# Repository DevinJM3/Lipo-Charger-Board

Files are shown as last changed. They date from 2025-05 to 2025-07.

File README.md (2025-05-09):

# LiPo Charger & Protection Board with 5V Output

PLACEHOLDER FOR IMAGE

## Overview

This project is a custom-designed Lithium Polymer battery charging and protection circuit with a regulated 5V output. Perfect for powering your portable electronics projects, this board offers a complete power management solution in a compact form factor.

## Features

- **LiPo Battery Charging**: Safe charging circuit for single-cell LiPo batteries
- **Battery Protection**: Overcharge, over-discharge, and short-circuit protection
- **5V Regulated Output**: Clean, stable 5V output regardless of battery voltage
- **Compact Design**: Minimized footprint for easy integration into projects
- **Status Indicators**: LED indicators for charging/full charge
- **USB Input**: Standard USB-C connector for charging and power input

## Technical Specifications

- **Input Voltage**: 5V DC via USB
- **Battery**: Single-cell 3.7V Lithium Polymer
- **Charging Current**: 500mA (configurable)
- **Output Voltage**: 5V ±0.1V
- **Maximum Output Current**: 2A continuous
- **Protection Features**:
  - Overcharge cutoff: 4.2V
  - Over-discharge cutoff: 2.8V
  - Short-circuit protection

## PCB Details

- **Dimensions**: XX mm × XX mm
- **Layers**: 2-layer PCB
- **Designed with**: KiCad 9.0

## Getting Started

### Bill of Materials

| Designator | Footprint | Quantity | Value | LCSC Part # |
|---|---|---|---|---|
| C1, C2 |0603 |2 |10uF |C19702 |
| C3 |0603 |1 |0.1uF |C14663 |
| C4, C5 |0603 |2 |22uF |C59461 |
| D1 |0603 |1 |RED |C965799 |
| D2 |0603 |1 |GREEN |C19171301 |
| D3 |D_SMA-SMB_Universal_Handsoldering |1 |SS34 |C908680 |
| D4, D5 |D_SMA-SMB_Universal_Handsoldering |2 |B340A |C85098 |
| D6 |Nexperia_CFP3_SOD-123W |1 |5.1v |C19077401 |
| J1 |JST_S2B-XH-A |1 |S2B-XH-A |C157931 |
| J2 |Usb-C |1 |USB_C_USB2.0_14P |C2988369 |
| L1 |WE-PD2_1054 |1 |22uH |C436465 |
| Q1, Q2 |SOT-23_Handsoldering |2 |SI2300A |C347480 |
| R1, R5 |0603 |2 |2k |C2907022 |
| R10 |0603 |1 |73.2k |C2933257 |
| R11, R7 |0603 |2 |10k |C98220 |
| R2, R3 |0603 |2 |1k |C103198 |
| R4 |0603 |1 |100 |C3016239 |
| R6 |0603 |1 |0.4 |C5126047 |
| R8, R9 |0603 |2 |5.1k |C3016319 |
| SW1 |SlideSwitch |1 |SK12D07VG4 |C393937 |
| U1 |SOIC-8 |1 |TP4056-42-ESOP8  |C725790 |
| U2 |SOT-23-6 |1 |MT3608 |C84817 |
| U3 |TSOT-23-6_HandSoldering |1 |FM2113 |C2832124 |

## Usage

1. Connect a LiPo battery to the BAT+ and BAT- terminals
2. Power the board via the USB connector
3. Connect your load to the 5V and GND output terminals
4. The charging indicator LED will illuminate red during charging and turn green when complete

## License

This project is released under the [MIT License](LICENSE).

## Contributing

Contributions to improve the design are welcome! Please feel free to submit issues or pull requests.

## Contact

If you have any questions or suggestions about this project, please open an issue on GitHub or contact me at Devin.Marx3@gmail.com.

---

*This is my first KiCad project! I appreciate any feedback or suggestions for improvement.*

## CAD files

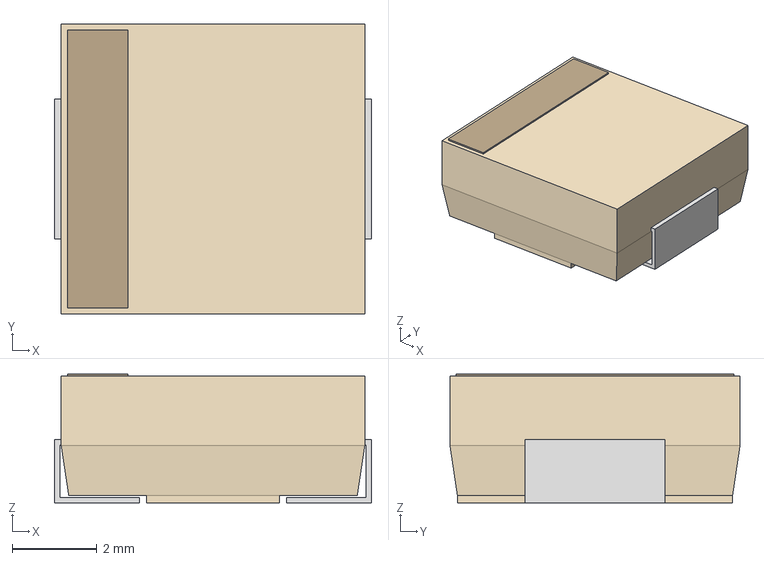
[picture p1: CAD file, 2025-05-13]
3D-Models/HY0630-100M.step
7.49 x 6.86 x 3.05 mm

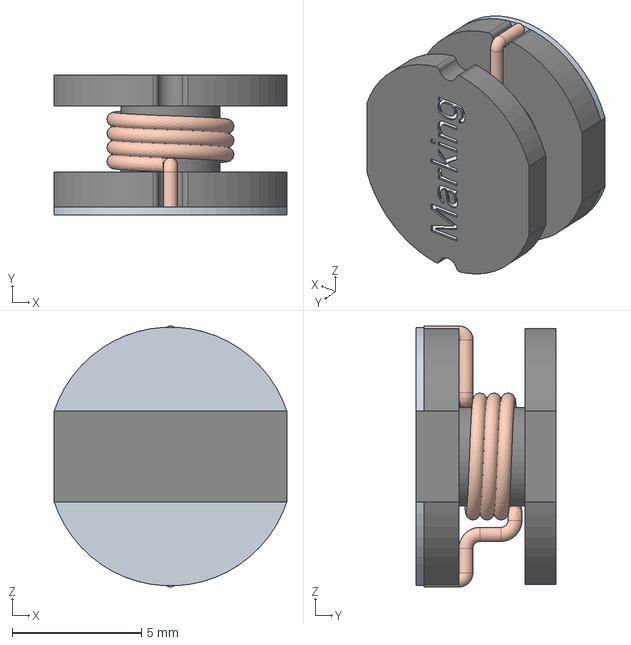
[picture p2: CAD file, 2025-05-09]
3D-Models/WE-PD2_1054.stp
9.00 x 5.40 x 10.1 mm

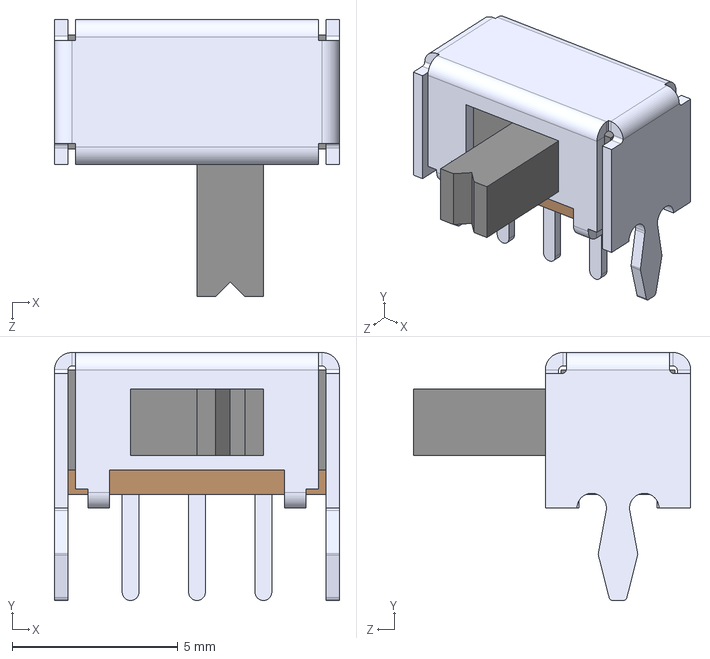
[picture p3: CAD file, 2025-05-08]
3D-Models/SK12D07VG4 - (SlideSwitch).STEP
8.61 x 7.49 x 8.38 mm

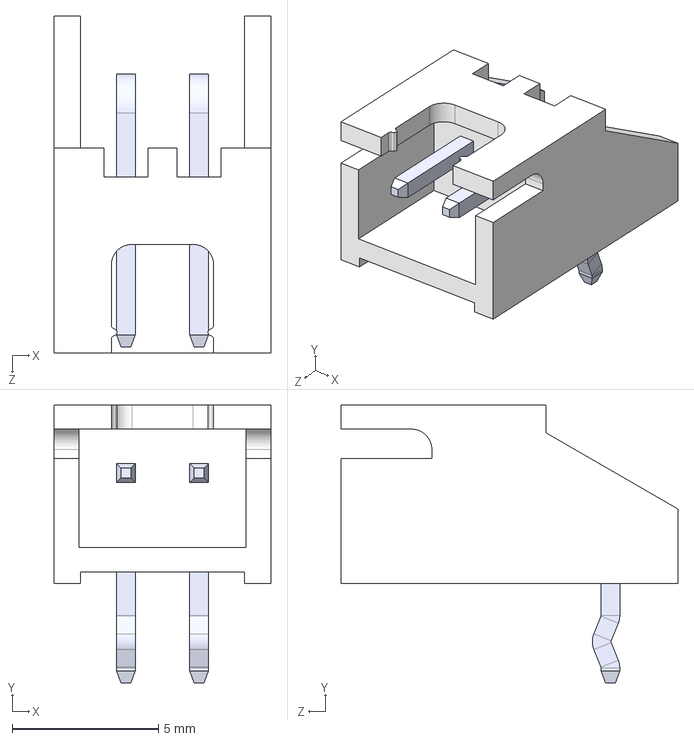
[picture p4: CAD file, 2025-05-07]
3D-Models/S2B-XH-A.step
7.40 x 9.50 x 11.5 mm
SxB-XH-A_2
pin^SxB-XH-A ass_bent x 2

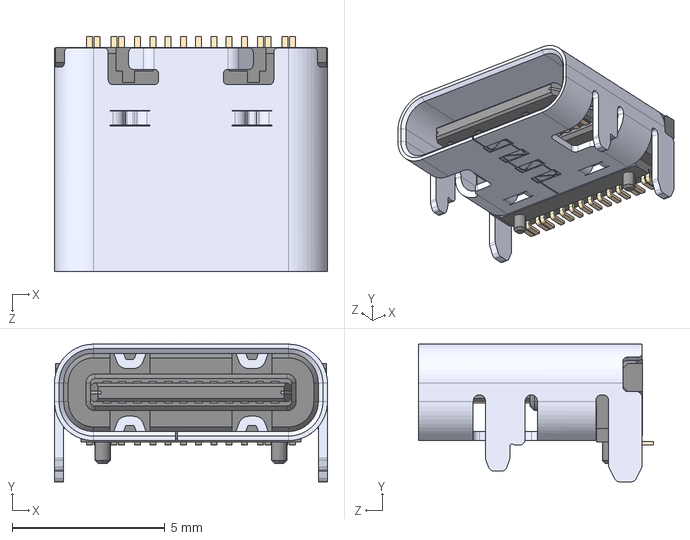
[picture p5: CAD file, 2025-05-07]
3D-Models/USB4105-GF-A-120.step
8.94 x 4.51 x 7.71 mm

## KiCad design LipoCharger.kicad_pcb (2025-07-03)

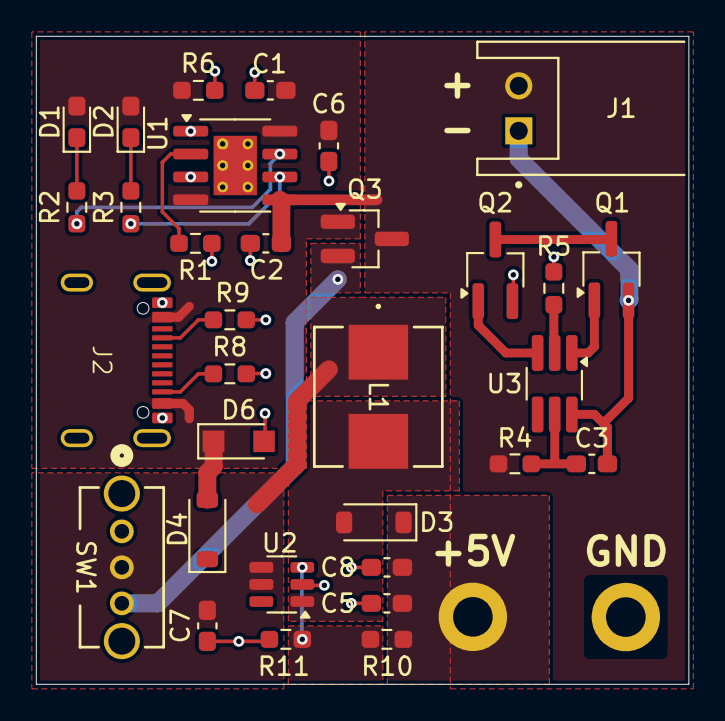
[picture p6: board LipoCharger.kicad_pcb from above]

Board: 4 copper layers, 36.2 x 36.0 mm, 35 parts (1 on the bottom side), 21 nets.

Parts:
C1, C2, C5, C8: 22uF; C_0603_1608Metric_Pad1.08x0.95mm_HandSolder
C3, C6, C7: 100nF; C_0603_1608Metric_Pad1.08x0.95mm_HandSolder
D1: RED; LED_0603_1608Metric_Pad1.05x0.95mm_HandSolder
D2: GREEN; LED_0603_1608Metric_Pad1.05x0.95mm_HandSolder
D3, D4: MBR230LSFT1G; D_SOD-123
D6: 5.1v; Nexperia_CFP3_SOD-123W
Devin M.: LOGO; PCB Logo (12.5x17)
GND_OUT1: MountingHole; MountingHole_2.2mm_M2_DIN965_Pad
J1: S2B-XH-A; JST_S2B-XH-A
J2: USB_C_Receptacle_USB2.0_14P; Usb-C
L1: 10uH; HY0630-100M-M
PWR_OUT1: MountingHole; MountingHole_2.2mm_M2_DIN965_Pad
Q1, Q2: SI2300A; TSOT-23_HandSoldering
Q3: HL 2305A; SOT-23_Handsoldering
R1, R5: 2k; R_0603_1608Metric_Pad0.98x0.95mm_HandSolder
R2, R3: 1k; R_0603_1608Metric_Pad0.98x0.95mm_HandSolder
R4: 100; R_0603_1608Metric_Pad0.98x0.95mm_HandSolder
R6: 10k; R_0603_1608Metric_Pad0.98x0.95mm_HandSolder
R8, R9: 5.1k; R_0603_1608Metric_Pad0.98x0.95mm_HandSolder
R10: 82k; R_0603_1608Metric_Pad0.98x0.95mm_HandSolder
R11: 11k; R_0603_1608Metric_Pad0.98x0.95mm_HandSolder
SW1: SK12D07VG4; SK12D07VG4 - (SlideSwitch)
U1: TP4056-42-ESOP8; SOIC-8-1EP_3.9x4.9mm_P1.27mm_EP2.41x3.3mm_ThermalVias
U2: MT3608; SOT-23-6
U3: FM2113; TSOT-23-6_HandSoldering

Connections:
+BATT: C2.1, J1.2, Q3.3 (D), R4.1, U1.5 (BAT)
-BATT: C3.2, J1.1, Q1.2 (S), U3.6 (VSS)
/SW: D3.2 (A), L1.2, U2.1 (SW)
BOOST_IN: C7.1, L1.1, SW1.2, U2.4 (EN), U2.5 (IN)
GND: C1.2, C2.2, C5.2, C6.2, C7.2, C8.2, D6.2 (A), GND_OUT1.1, J2.A1 (GND), Q2.2 (S), R1.2, R5.2, R6.1, R8.2, R9.2, R11.2, SW1.1, U1.1 (TEMP), U1.3 (GND), U1.9 (EPAD), U2.2 (GND)
unnamed: D1.1 (K), R2.1
unnamed: D2.1 (K), R3.1
unnamed: C5.1, C8.1, D3.1 (K), PWR_OUT1.1, R10.1
unnamed: D4.1 (K), Q3.2 (S), SW1.3
unnamed: J2.A5 (CC1), R9.1
unnamed: J2.B5 (CC2), R8.1
unnamed: Q1.3 (D), Q2.3 (D)
unnamed: Q1.1 (G), U3.1 (OD)
unnamed: Q2.1 (G), U3.3 (OC)
unnamed: R1.1, U1.2 (PROG)
unnamed: R2.2, U1.7 (~CHRG)
unnamed: R3.2, U1.6 (~STDBY)
unnamed: R10.2, R11.1, U2.3 (FB)
unnamed: R5.1, U3.2 (CS)
unnamed: C3.1, R4.2, U3.5 (VDD)
VBUS: C1.1, C6.1, D1.2 (A), D2.2 (A), D4.2 (A), D6.1 (K), J2.A4 (VBUS), Q3.1 (G), R6.2, U1.4 (V_{CC}), U1.8 (CE)

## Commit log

2025-05-06 Inital Commit
    [LipoCharger.kicad_pcb, LipoCharger.kicad_sch]
2025-05-07 Added the DW01 Battery Protection IC and started adding the USB-C port
    [LipoCharger.kicad_pcb, LipoCharger.kicad_sch, S2B-XH-A.step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]
2025-05-07 Replaced the DW01 with a FM2113
    The DW01 was not suited for a LIPO battery, the under voltage threshold was too low, so it was replaced with the FM2113 which has a much higher threshold
    [LipoCharger.kicad_pcb, LipoCharger.kicad_sch]
2025-05-08 Updated usb-c connector, added the 5v switcher, and started to find specific components for the swithcher
    [LipoCharger.kicad_pcb, LipoCharger.kicad_sch]
2025-05-08 Cleaned up schematic and added a slide switch
    * Added a slide switch for enabling the 5v Switcher
    * Added the USB protection and part numbers
    * Consolidated all of the symbols into the Symbols folder (instead of the _Library.pretty folder)
    [LipoCharger.kicad_pcb, LipoCharger.kicad_sch, SK12D07VG4 - (SlideSwitch).STEP]
2025-05-08 Fixed ERC errors
    [LipoCharger.kicad_sch]
2025-05-08 Started laying out the board
    Charging circuit should be finalized
    [LipoCharger.kicad_pcb]
2025-05-08 updated part numbers to add stock, added part numbers to each part
    [LipoCharger.kicad_pcb, LipoCharger.kicad_sch]
2025-05-09 Finished Layout and routing, just need to add mounting holes
    [LipoCharger.kicad_pcb, LipoCharger.kicad_sch, WE-PD2_1054.stp]
2025-05-09 Update KiCad.yml
    updated kicad actions version
2025-05-09 Made some small changes and added my "Logo"
    [LipoCharger.kicad_pcb]
2025-05-09 Updated kicad version and fixed drc
    [LipoCharger.kicad_pcb]
2025-05-12 Updated to add power pathing for usb and charging ic
    [LipoCharger.kicad_pcb, LipoCharger.kicad_sch]
2025-05-13 added the updated inductor and update the model for the PMOS mosfet (Should update the NMOS)
    [HY0630-100M.step, LipoCharger.kicad_pcb, LipoCharger.kicad_sch]
2025-05-15 Reoriented the PCB for the updated schematic layout
    [LipoCharger.kicad_pcb]
2025-05-15 Routed some traces (Almost finished routing)
    [LipoCharger.kicad_pcb]
2025-05-16 fixed nmos footprints
    [LipoCharger.kicad_pcb, LipoCharger.kicad_sch]
2025-05-23 Fixed most of the DRC
    [LipoCharger.kicad_pcb, LipoCharger.kicad_sch]
2025-05-23 Moved vias outside off of the pads
    [LipoCharger.kicad_pcb, LipoCharger.kicad_sch]
2025-05-30 Updated LCSC Part Numbers
    [LipoCharger.kicad_pcb, LipoCharger.kicad_sch]
2025-05-30 Fixed part number on BOM
    [LipoCharger.kicad_pcb, LipoCharger.kicad_sch]
2025-07-03 Fixed issue that would allow power to flow even thought the power switch is turned off
    [LipoCharger.kicad_pcb, LipoCharger.kicad_sch]
